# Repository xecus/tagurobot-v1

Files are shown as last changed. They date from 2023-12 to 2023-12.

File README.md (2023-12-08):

# Tagurobot V1

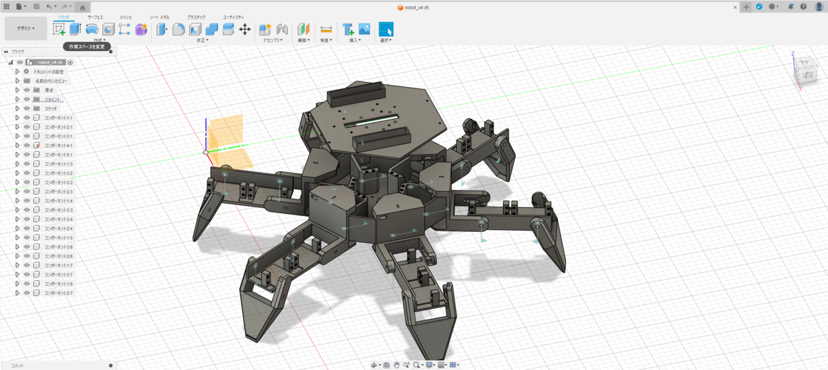
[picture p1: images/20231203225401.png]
Hexapod Image


本リポジトリは6脚ロボットの3Dモデルと制御用ソフトウェアの一部を格納したものになります。
詳細は下記の記事を御覧ください。

- [https://tech-blog.abeja.asia/entry/advent-2023-day08](https://tech-blog.abeja.asia/entry/advent-2023-day08)

# ディレクトリ・ファイル説明

- models
  - STL形式の3Dモデルが格納されています

- main.py
  - PC上、ロボット搭載のRaspberryPi上で動作可能なソフト
  - 制御シミュレーションやサーボモーターの制御が可能
  - 下記ライブラリを利用しています
    - [PyQT5](https://pypi.org/project/PyQt5/)
    - [adafruit_motor](https://github.com/adafruit/Adafruit_CircuitPython_Motor)
    - [adafruit_pca9685](https://github.com/adafruit/Adafruit_CircuitPython_PCA9685)

- gamepad_control.py
  - Gamepadと連動して各関節の駆動テストができます

# 3Dモデル・ソフトウェアの利用ポリシー
今回、知識のある理工学系の学生さんであれば誰でも作れるように、3Dモデルや一部ソフトウェアを公開しています。学習用途であればお気軽に使っていただいて構いません。
一方で、学習用途以外で利用したい方は事前にご相談ください。
相談先＝＞ [@xecus](https://twitter.com/xecus)

- LiPoバッテリーを利用する為、充電時やショートには十分ご注意ください
  - 大電流を流すことができるため、短絡すると非常に危険です
  - 回路を触るときは必ず電源OFFにしましょう
  - 充電時は過充電保護機能が搭載されている充電器を利用しましょう
- サーボモーターのトルクが強いため、指挟み事故等には注意
- 3Dプリンターの可動部・高温部に気をつける
  - FDMの場合、ノズル温度は約200度になります (PLAの場合)
- 工具を利用する場合は、怪我に注意する
  - はんだごて、ニッパー、カッターによる受傷に注意
  - 部品・工具の取り扱い、組み立て、テスト稼働には危険が伴います。作成時及び

作成物に起因した事故は当方では責任は負いかねます。(At your own risk)

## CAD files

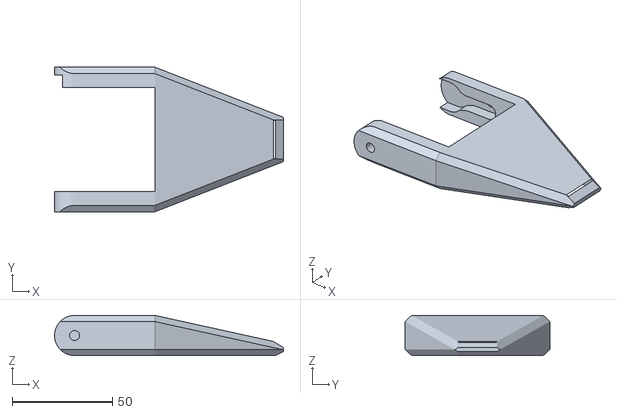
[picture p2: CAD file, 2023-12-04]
models/end_effector.stl
114.0 x 72.0 x 20.0

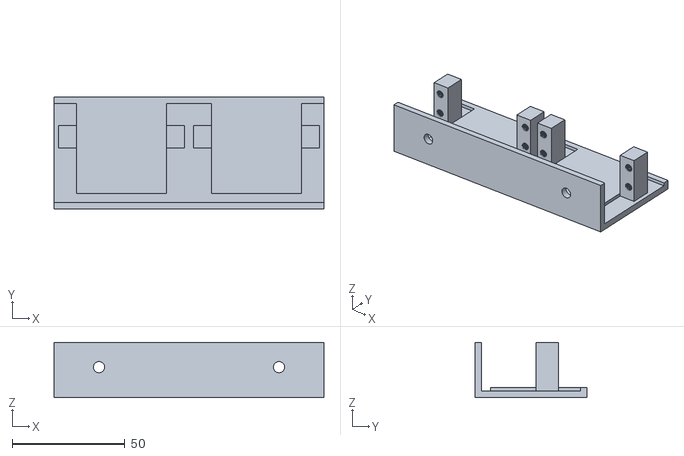
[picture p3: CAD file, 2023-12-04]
models/arm.stl
120.0 x 50.0 x 24.5

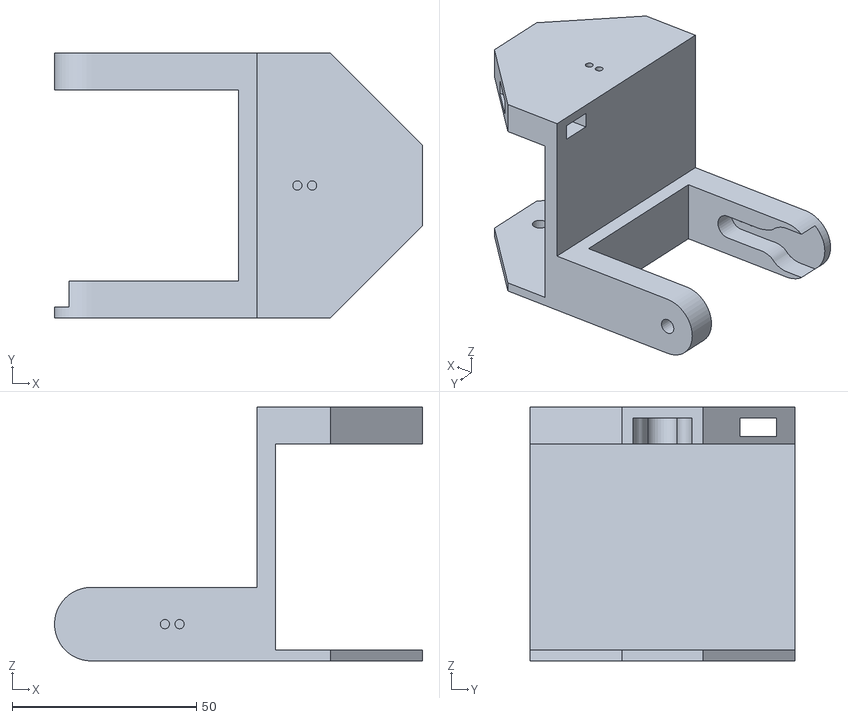
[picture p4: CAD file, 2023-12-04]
models/joint.stl
100.0 x 72.0 x 69.0

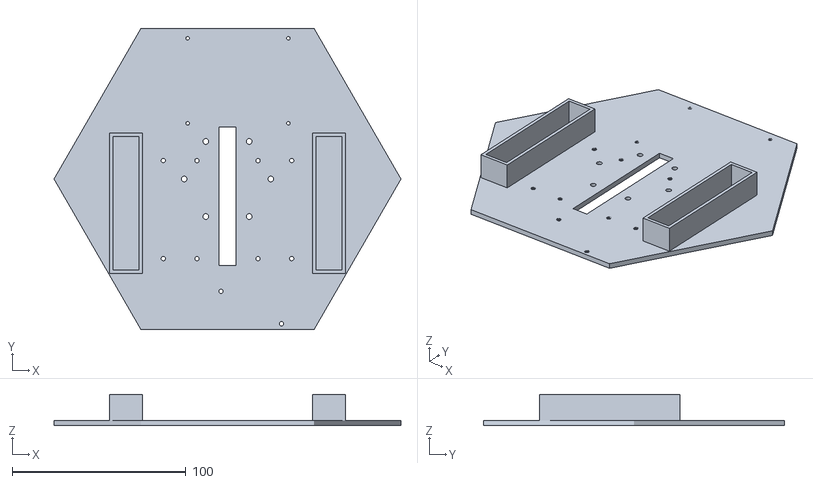
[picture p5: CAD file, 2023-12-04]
models/board.stl
200.0 x 173.2 x 18.0

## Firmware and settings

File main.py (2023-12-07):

# coding: utf-8
import enum
import math
import sys
import time

import numpy as np
from PyQt5 import QtWidgets
from PyQt5.QtCore import *
from PyQt5.QtGui import *
from PyQt5.QtGui import QColor, QFont, QPainter, QPen
from PyQt5.QtWidgets import *

ON_DEVELOP_MACHINE = True  # 開発マシンならTrue (RaspberryPi実機上ならFalse)

# I2C、PWMサーボモータードライバーの初期化 (実機のみ)
if not ON_DEVELOP_MACHINE:
    import busio
    from adafruit_motor import servo
    from adafruit_pca9685 import PCA9685
    from board import SCL, SDA


class JointGroupId(enum.IntEnum):
    A = 0
    B = 1
    C = 2
    D = 3
    E = 4
    F = 5


class JointType(enum.IntEnum):
    J1 = 0
    J2 = 1
    J3 = 2
    J4 = 3

# よく使う計算ロジック（回転行列の計算）


class CalcUtil():
    @classmethod
    def rotation(cls, u, t):
        r = np.array([[np.cos(t), -np.sin(t)], [np.sin(t), np.cos(t)]])
        return np.dot(r, u)

# サーボモーター制御クラス


class ServoMortors():
    def __init__(self):
        # シミュレーション上の論理的なサーボモーター角度と現実角度のOFFSET調整
        # ※サーボホーンの付け方に依存
        self.servo_theta1_offset = 90
        self.servo_theta2_offset = 140.0
        self.servo_theta3_offset = 150.0

        self.servos = []
        self.pca1 = None
        self.pca2 = None

    def deinit_servo_driver(self):
        self.pca1.deinit()
        self.pca2.deinit()

    def init_servo_driver(self):
        # I2C、PWMサーボモータードライバーの設定
        # 3個✕6関節=18個のモーターを制御するため、PCA9685搭載ボードを2枚利用
        # 注) アドレスがコンフリクトしないように、ハードウェア的に設定が必要
        i2c = busio.I2C(SCL, SDA)
        self.pca1 = PCA9685(i2c, address=0x40)
        self.pca1.frequency = 50
        self.pca2 = PCA9685(i2c, address=0x41)
        self.pca2.frequency = 50
        # サーボモーター制御クラスを初期化
        # 今回はDS3218(270度)とDS3218(180度)を利用
        # 注) パルス幅、ActuationRangeはサーボモーターの種類によって要変更
        self.servos = []
        for i in range(6):
            tmp = servo.Servo(
                self.pca1.channels[i],
                min_pulse=500,
                max_pulse=2500,
                actuation_range=270)
            self.servos.append(tmp)
        for i in range(6):
            tmp = servo.Servo(self.pca1.channels[6 + i],
                              min_pulse=500, max_pulse=2500, actuation_range=180)
            self.servos.append(tmp)
        for i in range(6):
            tmp = servo.Servo(
                self.pca2.channels[i],
                min_pulse=500,
                max_pulse=2500,
                actuation_range=180)
            self.servos.append(tmp)

    def _get_servo(self, joint_id, group_id):
        TYPE_A = 0
        TYPE_B = 6
        TYPE_C = 12
        if joint_id == JointType.J3:
            return self.servos[TYPE_A + group_id]
        if joint_id == JointType.J2:
            return self.servos[TYPE_B + group_id]
        if joint_id == JointType.J1:
            return self.servos[TYPE_C + group_id]
        raise Exception("Not found servo on mapping")

    def control(self, angles):
        theta1, theta2, theta3 = angles
        servo_theta1 = [0 for i in range(6)]
        servo_theta2 = [0 for i in range(6)]
        servo_theta3 = [0 for i in range(6)]
        # シミュレーション上の角度と、実際にサーボドライバーに指示する角度の変換
        for i in range(6):
            if (i < 3):
                servo_theta1[i] = math.radians(
                    self.servo_theta1_offset) + theta1[i]
                servo_theta2[i] = math.radians(
                    self.servo_theta2_offset) + theta2[i]
                servo_theta3[i] = math.radians(
                    self.servo_theta3_offset) - theta3[i]
            else:
                servo_theta1[i] = math.radians(
                    self.servo_theta1_offset) - (2.0 * math.pi - theta1[i])
                servo_theta2[i] = math.radians(
                    self.servo_theta2_offset) + theta2[i]
                servo_theta3[i] = math.radians(
                    self.servo_theta3_offset) - theta3[i]

        if ON_DEVELOP_MACHINE:
            return

        # サーボモータードライバーへの角度指示 (実際に動かす)
        for i in range(6):
            servo = self._get_servo(JointType.J1, i)
            t = math.degrees(servo_theta1[i])
            if t >= 0 and t <= 180:
                servo.angle = t
            else:
                print(f'(ERROR) J1[{i}]={t}')
            servo = self._get_servo(JointType.J2, i)
            t = math.degrees(servo_theta2[i])
            if t >= 0 and t <= 180:
                servo.angle = t
            else:
                print(f'(ERROR) J2[{i}]={t}')
            servo = self._get_servo(JointType.J3, i)
            t = math.degrees(servo_theta3[i])
            if t >= 0 and t <= 270:
                servo.angle = t
            else:
                print(f'(ERROR) J3[{i}]={t}')

    # 休眠姿勢
    def rest_position(self):
        for i in range(6):
            servo = self._get_servo(JointType.J3, i)
            servo.angle = 150
            time.sleep(0.1)
        for i in range(6):
            servo = self._get_servo(JointType.J2, i)
            servo.angle = 140
            time.sleep(0.1)
        for i in range(6):
            servo = self._get_servo(JointType.J1, i)
            servo.angle = 90
            time.sleep(0.1)

    # 立ち上がる
    def standing_position(self):
        start = 140
        stop = 90
        step = -10
        angle = start
        while angle >= stop:
            for i in range(6):
                servo = self._get_servo(JointType.J2, i)
                servo.angle = angle
                time.sleep(0.1)
            angle += step
        for i in range(6):
            servo = self._get_servo(JointType.J3, i)
            servo.angle = 150 + 40
            time.sleep(0.1)


class Hexapod():
    def __init__(self):
        self.init_position()

    def init_position(self):
        # Hexapodの諸元
        self.side_length = 0.1
        self.long1 = [0.04 for i in range(6)]
        self.long2 = [0.08 for i in range(6)]
        self.long3 = [0.08 for i in range(6)]
        # 各サーボモーターの角度 (シミュレーション上)
        self.theta1 = [math.radians(0) for i in range(6)]
        self.theta2 = [math.radians(0) for i in range(6)]
        self.theta3 = [math.radians(0) for i in range(6)]
        # X-Y座標面 (TOP VIEWからの座標面)
        self.leg_coords_topview = [[(0, 0) for j in range(6)]
                                   for i in range(4)]
        # X-Z'座標面 (各リンク機構をSIDE VIEWしたもの)
        self.leg_coords_sideview = [
            [(0, 0) for j in range(6)] for i in range(4)]
        # 順方向計算に使うパラメータ
        self.real_coords = [(0.15, -0.08) for i in range(6)]
        self.distance = [0.15 for i in range(6)]
        self.height = [-0.08 for i in range(6)]
        # 初期位置の決定
        for group_id in range(6):
            self.calc_backward(group_id)

    # 各関節角度のExport (サーボ制御系に渡すため)
    def export_angles(self):
        return [self.theta1, self.theta2, self.theta3]

    # 逆方向計算
    # 与えられた座標に持っていくために必要な関節角度(Theta2, Theta3)の計算
    # ※Theta1は別の場所で計算
    def calc_backward(self, group_id, apply=True):
        distance = self.distance[group_id]
        height = self.height[group_id]
        (real_x, real_y) = self.real_coords[group_id]
        real_x = distance if distance is not None else real_x
        real_y = height if height is not None else real_y

        l2 = self.long2[group_id]
        l3 = self.long3[group_id]
        real_x = real_x - self.long1[group_id]
        L = math.sqrt(real_x * real_x + real_y * real_y)
        J3, B, A, J2 = None, None, None, None
        ret = None
        try:
            J3 = math.acos((l2 * l2 + l3 * l3 - L * L) / (2 * l2 * l3))
            B = math.acos((L * L + l2 * l2 - l3 * l3) / (2 * L * l2))
            A = math.fabs(math.atan(real_y / real_x))
            # A = math.atan2(real_y, real_x)
            J2 = B - A
            theta2 = J2
            theta3 = -(math.pi - J3)
            ret = (theta2, theta3)
            if apply:
                self.theta2[group_id] = theta2
                self.theta3[group_id] = theta3
        except ValueError:
            return ret
        except ZeroDivisionError:
            return ret
        return ret

    # 順方向計算
    # 与えられた構造的パラメータと角度(Theta1, Theta2等)から関節位置を算出
    def calc_forward(self):
        r = self.side_length
        step = (math.pi * 2.0) / 6

        for i in range(6):
            l1 = self.long1[i]
            l2 = self.long2[i]
            l3 = self.long3[i]

            # TOP View
            x = r * math.cos(step * i)
            y = r * math.sin(step * i)
            self.leg_coords_topview[JointType.J1][i] = (x, y)

            Ru1 = CalcUtil.rotation((l1, 0), step * i - self.theta1[i])
            x = r * math.cos(step * i) + Ru1[0]
            y = r * math.sin(step * i) + Ru1[1]
            self.leg_coords_topview[JointType.J2][i] = (x, y)

            l2_top = CalcUtil.rotation((l2, 0), self.theta2[i])
            Ru2 = CalcUtil.rotation((l2_top[0], 0), step * i - self.theta1[i])
            x = r * math.cos(step * i) + Ru1[0] + Ru2[0]
            y = r * math.sin(step * i) + Ru1[1] + Ru2[1]
            self.leg_coords_topview[JointType.J3][i] = (x, y)

            l3_top = CalcUtil.rotation(
                (l3, 0), self.theta2[i] + self.theta3[i])
            Ru3 = CalcUtil.rotation((l3_top[0], 0), step * i - self.theta1[i])
            x = r * math.cos(step * i) + Ru1[0] + Ru2[0] + Ru3[0]
            y = r * math.sin(step * i) + Ru1[1] + Ru2[1] + Ru3[1]
            self.leg_coords_topview[JointType.J4][i] = (x, y)

            # Side View
            x = 0
            y = 0
            self.leg_coords_sideview[JointType.J1][i] = (x, y)

            x = l1
            y = 0
            self.leg_coords_sideview[JointType.J2][i] = (x, y)

            Ru1 = CalcUtil.rotation((l2, 0), self.theta2[i])
            x = self.long1[i] + Ru1[0]
            y = -Ru1[1]
            self.leg_coords_sideview[JointType.J3][i] = (x, y)

            Ru1 = CalcUtil.rotation((self.long2[i], 0), self.theta2[i])
            Ru2 = CalcUtil.rotation(
                (self.long3[i], 0), self.theta2[i] + self.theta3[i])
            x = self.long1[i] + Ru1[0] + Ru2[0]
            y = - (Ru1[1] + Ru2[1])
            self.leg_coords_sideview[JointType.J4][i] = (x, y)


class MainWidget(QtWidgets.QWidget):
    def __init__(self, parent=None):
        super(MainWidget, self).__init__()
        self.cnt = 0
        self.left_clicked_pos = None
        self.right_clicked_pos = None
        self.previous_right_clicked_pos = None

        # 実機の場合はモータードライバーを初期化する
        self.servo_mortors = ServoMortors()
        if not ON_DEVELOP_MACHINE:
            self.servo_mortors.init_servo_driver()
            self.servo_mortors.rest_position()
            self.servo_mortors.standing_position()
            time.sleep(3)

        self.hexapod = Hexapod()
        self.scale = 1000

        # 自動描画 (100msec秒毎に描画する)
        self.timer = QTimer(self)
        self.timer.timeout.connect(self.timer_func)
        self.timer.start(100)

    def timer_func(self):
        self.cnt += 1
        self.update()

    def mouseMoveEvent(self, event):
        mousex = event.x()
        mousey = event.y()

    def keyPressEvent(self, event):
        if event.key() == Qt.Key_Escape:
            self.close()

    def mousePressEvent(self, event):
        # 左クリック
        if event.button() == Qt.LeftButton:
            pos = event.pos()
            self.left_clicked_pos = pos
        # 右クリック
        if event.button() == Qt.RightButton:
            pos = event.pos()
            self.right_clicked_pos = pos
        self.repaint()

    def paintEvent(self, event):
        # self.hexapod.calc_forward()

        qp = QPainter()
        qp.begin(self)
        # qp.setRenderHint(QPainter.Antialiasing)

        JOINT_RADIUS_PX = 10
        TOP_VIEW_PANELS_X = 300
        TOP_VIEW_PANELS_Y = 300
        SIDE_VIEW_PANELS_X = 700
        SIDE_VIDE_PANELS_Y = 100
        PANEL_SIZE_X = 200
        PANEL_SIZE_Y = 150

        qp.setPen(QColor(Qt.red))
        qp.setFont(QFont('Arial', 20))
        qp.drawText(10, 50, f'cnt={self.cnt}')

        """
        # 左クリックで手動で関節を動かす (SIDE_VIEW_PANEL)
        for i in range(6):
            base_x = PANEL_SIZE_X * i
            base_y = PANEL_SIZE_Y
            group_id = None
            if self.left_clicked_pos is not None:
                mousex_in_global = self.left_clicked_pos.x()
                mousey_in_global = self.left_clicked_pos.y()
                mousex_in_panels = mousex_in_global - SIDE_VIEW_PANELS_X
                mousey_in_panels = mousey_in_global - SIDE_VIDE_PANELS_Y
                group_id = int(mousex_in_panels / PANEL_SIZE_X)
            if group_id == i:
                real_x = (mousex_in_panels - base_x) / self.scale
                real_y = - (mousey_in_panels - base_y) / self.scale
                self.hexapod.real_coords[group_id] = (real_x, real_y)
                self.hexapod.calc_forward()

        # 右クリックで手動で関節を動かす (Theta1への反映)
        if self.right_clicked_pos != self.previous_right_clicked_pos:
            target_joint = JointGroupId.A
            original_mousex = self.right_clicked_pos.x()
            original_mousey = self.right_clicked_pos.y()
            real_x = (original_mousex - TOP_VIEW_PANELS_X) / self.scale
            real_y = (original_mousey - TOP_VIEW_PANELS_Y) / self.scale
            (x1, y1) = self.hexapod.leg_coords_topview[JointType.J1][target_joint]
            x_diff1 = real_x - x1
            y_diff1 = real_y - y1
            self.hexapod.theta1[target_joint] = math.atan2(-y_diff1, x_diff1) + (2.0*math.pi/6.0) * target_joint
            self.hexapod.distance[target_joint] = math.sqrt(x_diff1*x_diff1 + y_diff1*y_diff1)
            self.hexapod.calc_forward()
            #qp.setPen(QPen(Qt.green, 3, Qt.SolidLine))
            #qp.drawLine(original_mousex, original_mousey,
            #            round(x1 * self.scale + TOP_VIEW_PANELS_X), round(y1 * self.scale + TOP_VIEW_PANELS_Y))
            self.previous_right_clicked_pos = self.right_clicked_pos
        """

        #
        # 足を制御する
        #
        def relu(a):
            return a if a > 0 else 0
        # 1周期の分割数 (高ければ高いほど小刻みな運動)
        num_divide = 100
        # 一歩の歩幅 (m)
        stroke_step_length_a = 0.03
        # 一歩の高さ
        stroke_step_length_b = 0.01
        # TOP_VIEWにおける関節と足の定位置までの距離
        distance_a = 0.1
        # SIDE_VIEWから見た時の関節と地面までの距離
        distance_b = -0.08
        # よく使い回す値
        tmp1 = 2.0 * math.pi / 6.0
        tmp2 = 2.0 * math.pi / num_divide
        # 各関節の位置計算
        for target_joint in range(6):
            # 位相角の計算
            phase_diff1 = math.pi / 2 if (target_joint % 2 != 0) else 0
            phase_diff2 = math.pi if (target_joint % 2 != 0) else 0
            # J1からdistance_a[m]離れた位置を計算する (TOP_VIEWでみた足を着地すべき場所)
            (x1,
             y1) = self.hexapod.leg_coords_topview[JointType.J1][target_joint]
            x = distance_a * math.cos(tmp1 * target_joint)
            y = distance_a * math.sin(tmp1 * target_joint)
            y -= stroke_step_length_a * \
                math.fabs(math.sin(tmp2 * self.cnt + phase_diff1))
            # 角度、距離などを変更
            self.hexapod.theta1[target_joint] = math.atan2(
                -y, x) + (2.0 * math.pi / 6.0) * target_joint
            self.hexapod.distance[target_joint] = math.sqrt(x * x + y * y)
            self.hexapod.height[target_joint] = distance_b + math.fabs(
                relu(stroke_step_length_b * math.sin(tmp2 * 2 * self.cnt + phase_diff2)))
            # TOP VIEWにおける可動範囲の描画
            tmp_x = x1 + distance_a * math.cos(tmp1 * target_joint)
            tmp_y = y1 + distance_a * math.sin(tmp1 * target_joint)
            qp.setPen(QPen(Qt.red, 3, Qt.SolidLine))
            qp.drawLine(
                round(
                    (tmp_x) * self.scale + TOP_VIEW_PANELS_X),
                round(
                    (tmp_y - stroke_step_length_a) * self.scale + TOP_VIEW_PANELS_Y),
                round(
                    (tmp_x) * self.scale + TOP_VIEW_PANELS_X),
                round(
                    (tmp_y + stroke_step_length_a) * self.scale + TOP_VIEW_PANELS_Y))

        # 各関節角度の計算 (逆方向計算)
        for i in range(6):
            self.hexapod.calc_backward(i)
        # 各関節位置の計算 (順方向計算)
        self.hexapod.calc_forward()
        # 内部角度情報のエクスポート
        angles = self.hexapod.export_angles()
        # 実際のサーボモーターの制御
        self.servo_mortors.control(angles)

        # TOP Viewパネルの描画
        qp.save()
        qp.translate(TOP_VIEW_PANELS_X, TOP_VIEW_PANELS_Y)
        qp.setBrush(QColor(0, 0, 255))
        qp.setPen(Qt.NoPen)
        qp.drawEllipse(-5, -5, 10, 10)
        for j in range(4):
            point_r = 10
            for i, (x, y) in enumerate(self.hexapod.leg_coords_topview[j]):
                tmp_x = round(x * self.scale - point_r / 2)
                tmp_y = round(y * self.scale - point_r / 2)
                qp.setBrush(QColor(0, 0, 255))
                qp.setPen(Qt.NoPen)
                qp.drawEllipse(tmp_x, tmp_y, point_r, point_r)
                tmp_x = round(x * self.scale + 15)
                tmp_y = round(y * self.scale + 15)
                qp.setPen(QColor(Qt.red))
                qp.setFont(QFont('Arial', 10))
                if j == 3:
                    qp.drawText(tmp_x, tmp_y, f'J{j+1} ({x:.2f},{y:.2f})')
                else:
                    qp.drawText(tmp_x, tmp_y, f'J{j+1}')

        # Draw Hexagon
        for i in range(6):
            (x1, y1) = self.hexapod.leg_coords_topview[JointType.J1][i]
            (x2, y2) = self.hexapod.leg_coords_topview[JointType.J1][(
                i + 1) % 6]
            x1 = round(x1 * self.scale)
            y1 = round(y1 * self.scale)
            x2 = round(x2 * self.scale)
            y2 = round(y2 * self.scale)
            qp.setBrush(QColor(0, 0, 255))
            qp.setPen(QColor(Qt.blue))
            qp.drawLine(x1, y1, x2, y2)
        # Draw guide lines on Hexagon
        for i in range(6):
            distance = 0.2
            (x1, y1) = self.hexapod.leg_coords_topview[JointType.J1][i]
            x1 = round(x1 * self.scale)
            y1 = round(y1 * self.scale)
            x2 = round(
                x1 +
                distance *
                math.cos(
                    (2.0 *
                     math.pi /
                     6.0) *
                    i) *
                self.scale)
            y2 = round(
                y1 +
                distance *
                math.sin(
                    (2.0 *
                     math.pi /
                     6.0) *
                    i) *
                self.scale)
            qp.setPen(QColor(Qt.red))
            qp.drawLine(x1, y1, x2, y2)
        # Draw link between each joints
        for j in range(3):
            for i in range(6):
                (x1, y1) = self.hexapod.leg_coords_topview[j][i]
                (x2, y2) = self.hexapod.leg_coords_topview[j + 1][i]
                x1 = round(x1 * self.scale)
                y1 = round(y1 * self.scale)
                x2 = round(x2 * self.scale)
                y2 = round(y2 * self.scale)
                qp.setPen(QColor(Qt.blue))
                qp.drawLine(x1, y1, x2, y2)
        qp.restore()
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

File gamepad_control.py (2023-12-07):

import os

import pygame

TYPE_A = 0
TYPE_B = 6
TYPE_C = 12
ON_DEVELOP_MACHINE = True

if not ON_DEVELOP_MACHINE:
    import busio
    from adafruit_motor import servo
    from adafruit_pca9685 import PCA9685
    from board import SCL, SDA

# RaspberryPi上で動かす場合、必要になる
os.environ["SDL_VIDEODRIVER"] = "dummy"
pygame.init()
joystick = pygame.joystick.Joystick(0)
joystick.init()

i2c = None
pca1 = None
pca2 = None
servos = []


def init_servo():
    i2c = busio.I2C(SCL, SDA)
    pca1 = PCA9685(i2c, address=0x40)
    pca1.frequency = 50
    pca2 = PCA9685(i2c, address=0x41)
    pca2.frequency = 50
    for i in range(6):
        tmp = servo.Servo(pca1.channels[i],
                          min_pulse=500, max_pulse=2500, actuation_range=270)
        servos.append(tmp)
    for i in range(6):
        tmp = servo.Servo(pca1.channels[6 + i],
                          min_pulse=500, max_pulse=2500, actuation_range=180)
        servos.append(tmp)
    for i in range(6):
        tmp = servo.Servo(pca2.channels[i],
                          min_pulse=500, max_pulse=2500, actuation_range=180)
        servos.append(tmp)

# 線形補間をするための関数を返す


def make_interpolater(left_min, left_max, right_min, right_max):
    left_span = left_max - left_min
    right_span = right_max - right_min
    scale_factor = float(right_span) / float(left_span)

    def tmp(value):
        return right_min + (value - left_min) * scale_factor
    return tmp


if __name__ == '__main__':

    if not ON_DEVELOP_MACHINE:
        init_servo()

    # 操作する関節番号
    target1 = 0
    # 操作する関節種類の指定 (3種類)
    target2 = 0

    while True:
        # GamePadからの入力を取得
        if pygame.event.get():
            gamepad_data = {
                "joy_lx": joystick.get_axis(0),
                "joy_ly": joystick.get_axis(1),
                "joy_ry": joystick.get_axis(2),
                "joy_rx": joystick.get_axis(3),
                "hat_x": joystick.get_hat(0)[0],
                "hat_y": joystick.get_hat(0)[1],
                "btn_a": joystick.get_button(0),
                "btn_b": joystick.get_button(1),
                "btn_x": joystick.get_button(2),
                "btn_y": joystick.get_button(3),
                "btn_lb": joystick.get_button(4),
                "btn_rb": joystick.get_button(5),
                "btn_back": joystick.get_button(6),
                "btn_start": joystick.get_button(7),
                "btn_guide": joystick.get_button(8),
                "btn_joyl": joystick.get_button(9),
                "btn_joyr": joystick.get_button(10)
            }
            print(gamepad_data)

            value = gamepad_data['joy_lx']
            if target2 == 0:
                # 150度の±90度で動かす
                if not ON_DEVELOP_MACHINE:
                    servos[TYPE_A + \
                        target1].angle = make_interpolater(-1.0, +1.0, 150 - 90, 150 + 90)(value)
            if target2 == 1:
                # 140度の±30度で動かす
                if not ON_DEVELOP_MACHINE:
                    servos[TYPE_B + \
                        target1].angle = make_interpolater(-1.0, +1.0, 140 - 30, 140 + 30)(value)
            if target2 == 2:
                # 90度の±60度で動かす
                if not ON_DEVELOP_MACHINE:
                    servos[TYPE_C + \
                        target1].angle = make_interpolater(-1.0, +1.0, 90 - 60, 90 + 60)(value)

            if gamepad_data['btn_x']:
                target1 += 1
                if target1 == 6:
                    target1 = 0
            if gamepad_data['btn_y']:
                target2 += 1
                if target2 == 3:
                    target2 = 0
